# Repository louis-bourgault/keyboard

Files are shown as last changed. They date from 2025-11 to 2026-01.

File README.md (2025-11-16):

# keyboard
*my project for hack club blueprint*

## Render (made in blender, not exact but this is what I'm going for. I had some fun with lighting in this one)
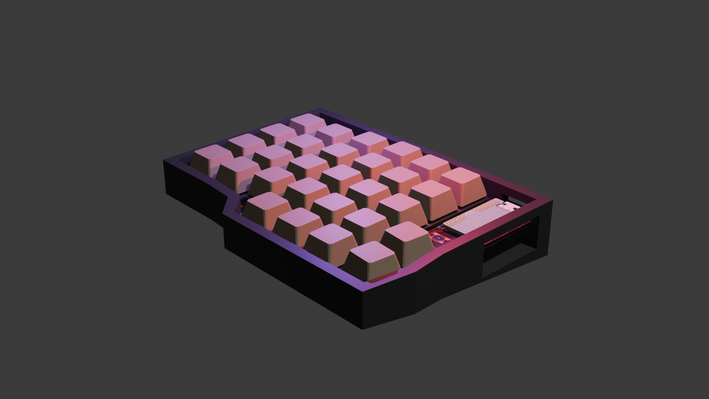
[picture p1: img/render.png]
Blender Render

### Boring edition without the lighting
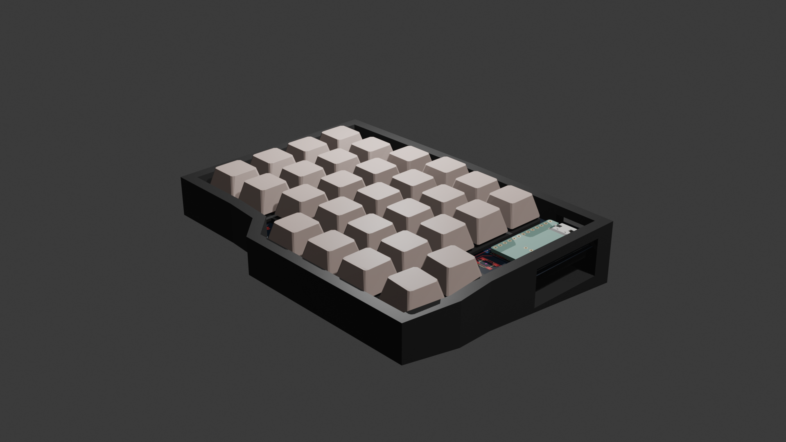
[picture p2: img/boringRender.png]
Boring Render


My design for a lily58 inspired split wireless keyboard using ergogen and kicad. It uses the NRF52840 chipset, and 3d printed parts mostly

One of my friends has significant wrist pain because his laptop keyboard is terrible. A few months ago we were planning to make a keyboard together and made things in Ergogen but never got that much further than that. Now, I have put things into kicad and done a bit more work in preparing things to be actually manufactured.
This is designed to be pretty much as cheap a keyboard as it is possible to manufacture, aiming for about AU$50 per keyboard (I am making two of these, so more like $100 total). This comes out to about $30 USD per keyboard, $60 total.

## Design
### PCB
- Ergogen for PCB design and layout drafting. It is a very simple, user friendly and powerful program. You define layouts for rows and columns, and nets to connect them
  - Note: In my Ergogen file there is a single net that was not correct, and I had to route manually in KiCad. This is the upper thumb cluster key.
- KiCad for routing the pcb. Ergogen creates the nets, so I only have to route it -- as such, there is no kicad schematic file, just a pcb file that I edited to design
- PCB: AllPcb. They had a cheap offer which let me get everything for a $2, including delivery.

### Case Design:
I use Fusion 360 in school, and am quite used to the program, so that is what I will use. As of November 1 2025, I haven't fully decided on the design -- but what I am thinking is that i will use a clean looking white coloured case, with an oiled plywood or even Jarrah laser cut bottom plate that fits in. My school has a good 3d printer (bambu p1s) and a laser cutter, so I can get everything designed there.
Ergogen outputs a DXF file for the bottom shape of the case, which is defined through the ```outlines``` section of ergogen.yml. This is the shape that I use for the outline of my PCB, so I will need to make an offset line around and use that as the case outline.
Also, since I will be taking this keyboard to and from school, I will make a hinging case to place the two halves in with foam padding for safety.

### Software
I will probably just go with zmk for this. One thing that is important to me is for the keyboard to run both wired and wireless - eg I plug one half with a usb C to A port into a school computer, and then that half talks to the other half and I can use it on computers without Bluetooth support; but I believe that QMK has this function so I will just use that. Potentially, if I have extra time, then I could code something custom in C, but I am not sure whether this is feasible at this point and with exams coming up.

Note: this software is in a seperate repo because of the way that ZMK works. The repo is [louis-bourgault/zmk-config](https://github.com/louis-bourgault/zmk-config)

# Images
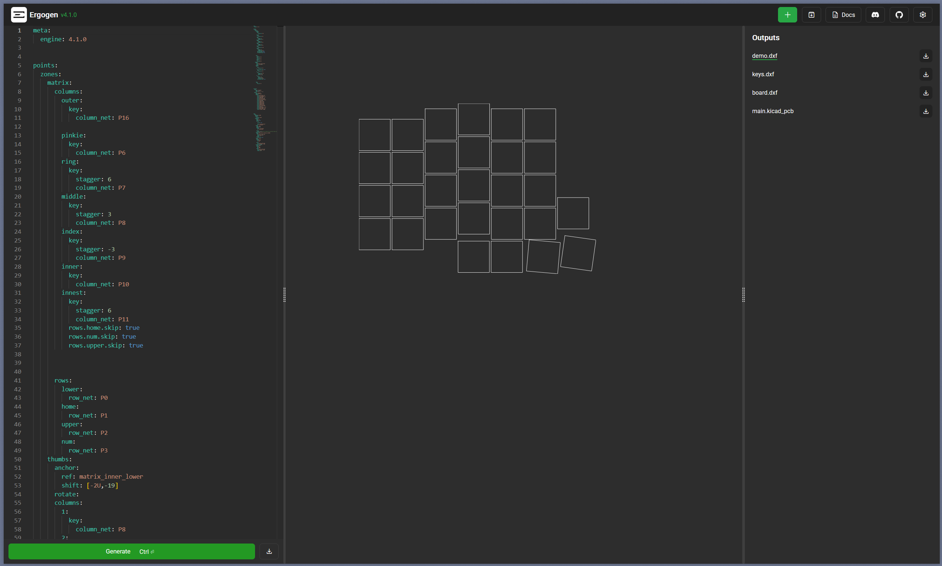
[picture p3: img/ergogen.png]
Initial Ergogen Design

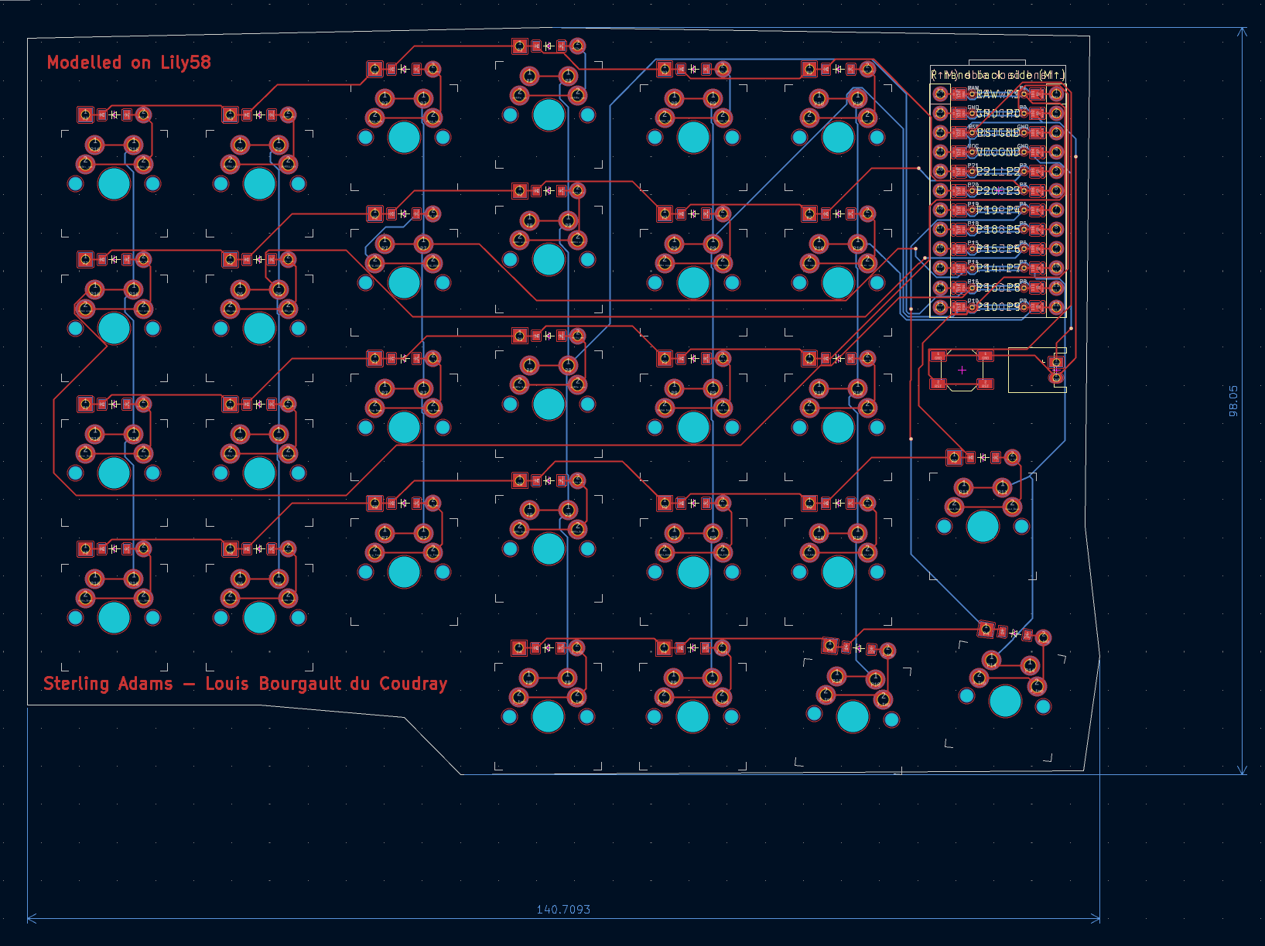
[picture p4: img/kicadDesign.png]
Kicad PCB, ready to be ordered

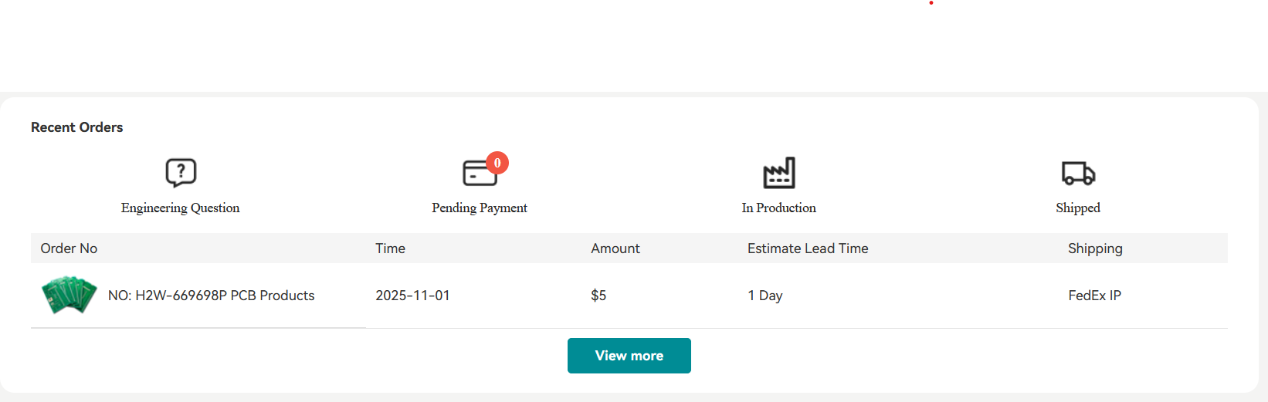
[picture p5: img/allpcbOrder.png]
Allpcb Order

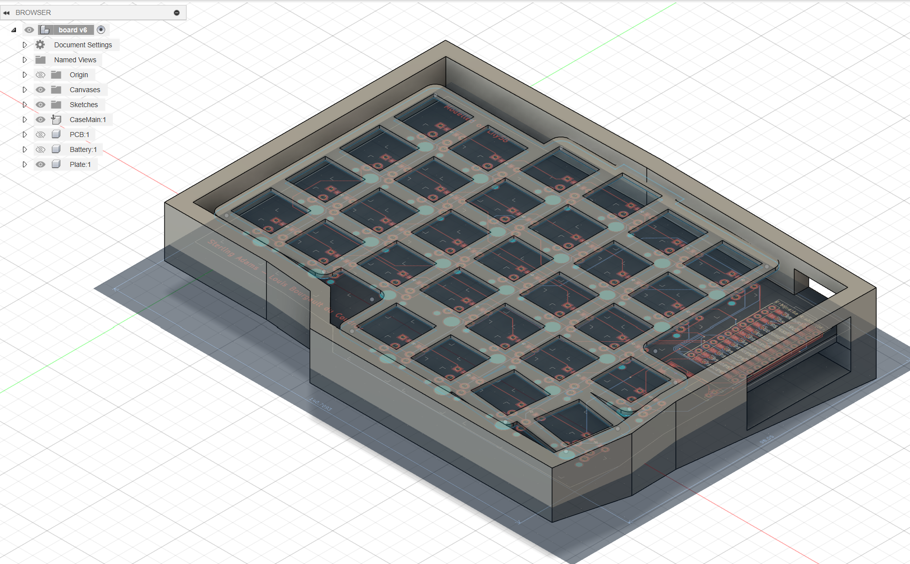
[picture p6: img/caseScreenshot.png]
Screenshot of case design in Fusion 360


# Bill of Materials

|Component Type |Item Link |Quantity needed|Relevant Specifications |Tax % (if not included)|Price each (AUD)|Total Cost (AUD)|Total Cost (USD) (using 1 AUD = 0.65 USD)|Running Cost (AUD|Running Cost (USD)|Note |
|---|---|---|---|---|---|---|---|---|---|---|
|Battery * 4 |https://www.aliexpress.com/item/1005006924508264.html?mp=1|1 |3.7v, 400mAh, 53x36x6mm, JSTPH|0.00% |$18.40 |$18.40 |$11.96 |$18.40 |$11.96 | |
|NRF52840 |https://www.aliexpress.com/item/1005006035267231.html? |4 | |10.00% |$5.65 |$24.86 |$16.16 |$43.26 |$28.12 | |
|Keyboard Switch * 110|https://www.aliexpress.com/item/1005006376024657.html?mp=1|1 |Gateron Brown * 110 |10.00% |$18.33 |$20.16 |$13.11 |$63.42 |$41.22 |This is using my Welcome Deal on Aliexpress |
|Keyboard Switch * 10 |https://www.aliexpress.com/item/1005006376024657.html?mp=1|1 |Gateron Yellow * 10 |10.00% |$4.70 |$5.17 |$3.36 |$68.59 |$44.59 |Supplemental Switches, not on welcome deal so substantially more expensive. Will use different type of switch (linear instead of tactile) for modifier keys|
|Diodes * 200 |https://www.aliexpress.com/item/1005009896621714.html |1 |Basic 1n4148 diodes |10.00% |$5.94 |$6.53 |$4.25 |$75.13 |$48.83 | |
|PCB * 5 |AllPCB |1 | |0.00% |$2.14 |$2.14 |$1.39 |$77.27 |$50.22 |already purchased |
|Keycaps * 80 |https://www.aliexpress.com/item/1005007415198959.html?mp=1|2 | |10.00% |$13.58 |$29.88 |$19.42 |$107.14 |$69.64 | |

# Note on Pricing
Since a lot of these sites have little fees that are hard to deal with on a one by one basis (such as payment processing fees, et cetera). So, the final numbers as given at checkout are slightly different.
Additionally, there is a chance that these prices may fluctuate. If they go up at all, I am able to cover the cost (I am willing to spend a bit of my money on this, and don't need a grant for all of it).

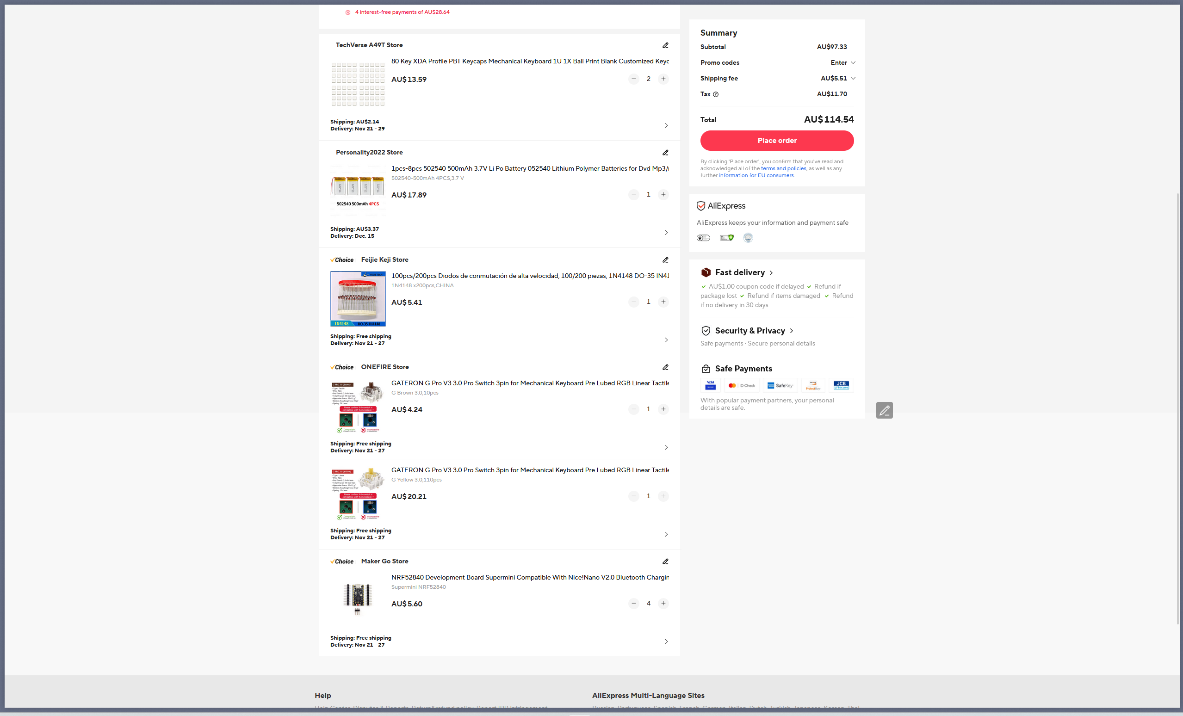
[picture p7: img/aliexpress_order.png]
Aliexpress Order

Allpcb
Note: this order actually cost me $2.14, it's just not showing the right amount because that was a one time discount

Prices:
- Aliexpress: AU$114.54
- Allpcb: AU$2.14

Total: AU$116.68
In USD: US$76.20
Note: if I do not qualify for a full support, i can cover a portion of it.

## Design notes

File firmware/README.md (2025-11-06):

# Firmware

Since this board is bluetooth, it uses the ZMK firmware setup, and it is reccomended to keep this in a different repo since ZMK compiles through Github actions.
This repository is [louis-bourgault/zmk-config](https://github.com/louis-bourgault/zmk-config)

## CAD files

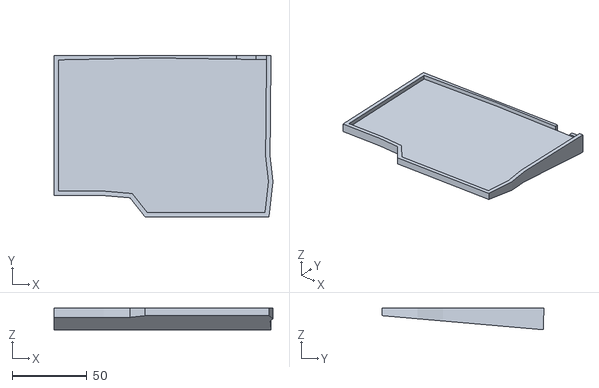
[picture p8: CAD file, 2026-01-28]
case/newcase.stl
146.7 x 108.2 x 14.4

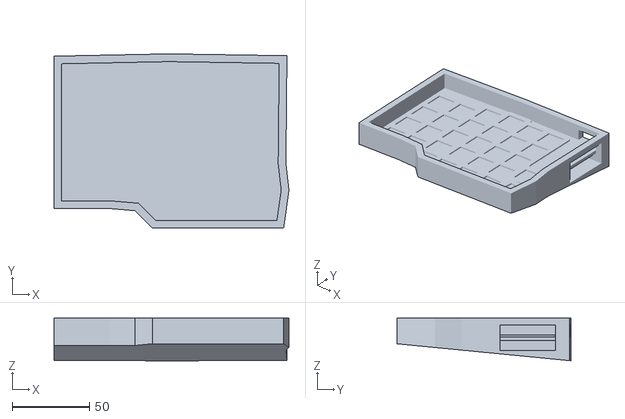
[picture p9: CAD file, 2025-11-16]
case/board v6.stl
151.8 x 112.5 x 27.5

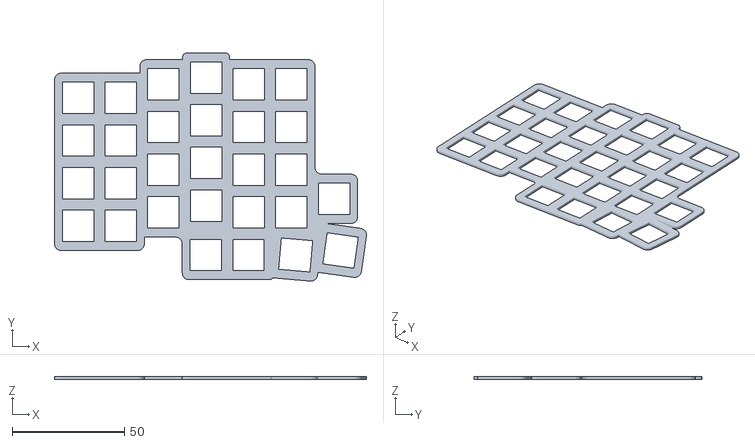
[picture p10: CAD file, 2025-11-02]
case/plate_v1.stl
139.0 x 101.7 x 1.20

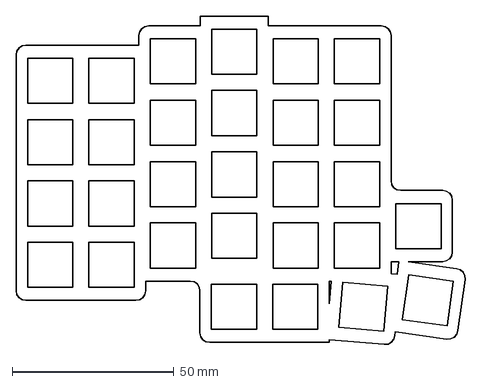
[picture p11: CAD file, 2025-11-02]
case/cutout.dxf
139.2 x 101.8 mm

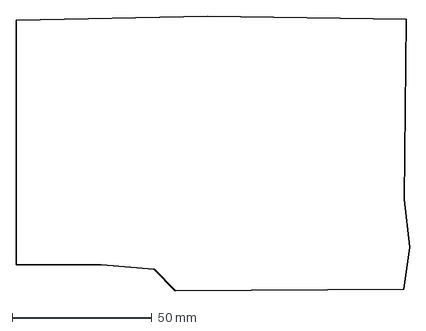
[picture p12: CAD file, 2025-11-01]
case/board.dxf
140.7 x 98.1 mm

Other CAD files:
case/case_v1.step
case/case_v1.3mf
case/case_v1.f3d
case/case_v1.stl
case/newcase v2.f3d
roughmodel.blend

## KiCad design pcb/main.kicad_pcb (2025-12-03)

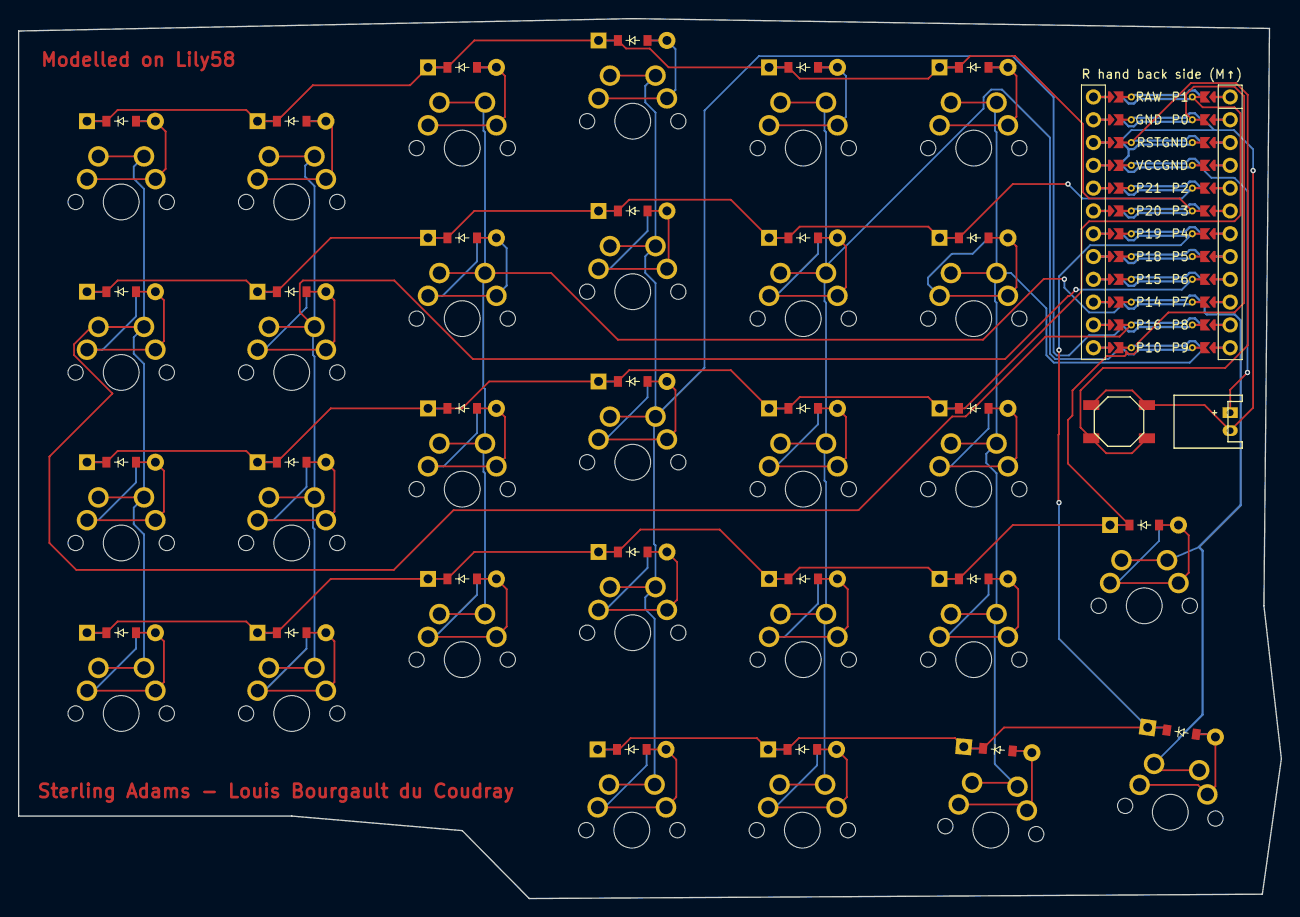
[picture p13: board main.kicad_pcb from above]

Board: 2 copper layers, 140.7 x 98.1 mm, 61 parts (0 on the bottom side), 44 nets.

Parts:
B1: SW_TACT_ALPS_SKQGABE010
D1, D2, D3, D4, D5, D6, D7, D8, D9, D10, D11, D12, D13, D14, D15, D16, D17, D18, D19, D20, D21, D22, D23, D24, D25, D26, D27, D28, D29: ComboDiode
JST1: JST_PH_S2B-PH-K_02x2.00mm_Angled
MCU1: mcu_supermini_nrf52840
S1, S2, S3, S4, S5, S6, S7, S8, S9, S10, S11, S12, S13, S14, S15, S16, S17, S18, S19, S20, S21, S22, S23, S24, S25, S26, S27, S28, S29: MX

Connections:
1_top: D26.2, S26.2
2_top: D27.2, S27.2
3_top: D28.2, S28.2
4_top: D29.2, S29.2
GND: B1.1, JST1.2, MCU1.103, MCU1.104, MCU1.123
P0: D1.1, D5.1, D9.1, D13.1, D17.1, D21.1, D25.1, MCU1.102
P1: D2.1, D6.1, D10.1, D14.1, D18.1, D22.1, MCU1.101
P2: D3.1, D7.1, D11.1, D15.1, D19.1, D23.1, MCU1.105
P3: D4.1, D8.1, D12.1, D16.1, D20.1, D24.1, MCU1.106
P4: D26.1, D27.1, D28.1, D29.1, MCU1.107
P6: MCU1.109, S5.1, S6.1, S7.1, S8.1
P7: MCU1.110, S9.1, S10.1, S11.1, S12.1
P8: MCU1.111, S13.1, S14.1, S15.1, S16.1, S26.1
P9: MCU1.112, S17.1, S18.1, S19.1, S20.1, S27.1
P10: MCU1.113, S21.1, S22.1, S23.1, S24.1, S28.1
P14: MCU1.115, S29.1
P16: MCU1.114, S1.1, S2.1, S3.1, S4.1
RST: B1.2, MCU1.122
VCC: JST1.1, MCU1.121
index_home: D18.2, S18.2
index_lower: D17.2, S17.2
index_num: D20.2, S20.2
index_upper: D19.2, S19.2
inner_home: D22.2, S22.2
inner_lower: D21.2, S21.2
inner_num: D24.2, S24.2
inner_upper: D23.2, S23.2
innest_lower: D25.2, S25.2
middle_home: D14.2, S14.2
middle_lower: D13.2, S13.2
middle_num: D16.2, S16.2
middle_upper: D15.2, S15.2
outer_home: D2.2, S2.2
outer_lower: D1.2, S1.2
outer_num: D4.2, S4.2
outer_upper: D3.2, S3.2
pinkie_home: D6.2, S6.2
pinkie_lower: D5.2, S5.2
pinkie_num: D8.2, S8.2
pinkie_upper: D7.2, S7.2
ring_home: D10.2, S10.2
ring_lower: D9.2, S9.2
ring_num: D12.2, S12.2
ring_upper: D11.2, S11.2

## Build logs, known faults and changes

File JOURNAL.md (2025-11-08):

<!--
  ===================    !!READ THIS NOTICE!!   ====================
  DO NOT edit this file manually. Your changes WILL BE OVERWRITTEN!
  This journal is auto generated and updated by Hack Club Blueprint.
  To edit this file, please edit your journal entries on Blueprint.
  ==================================================================
-->

## 11/1/2025 2:10 PM - First Journal Entry  

This is a project that i have been working on for a bit. It's for me and a friend from school, who has wrist pain and his laptop keyboard is absolutely terrible. The ergogen config was made about a month ago and i haven't worked on it for a while because i was busy but i routed it today on the pcb in kicad and prepared it to be ordered from allpcb.
The setup is reversible and designed to cost about AU$50 (about US$30) per pair of boards -- i haven't made a full BOM yet but that's next i think.
  

## 11/1/2025 2:50 PM - Fixed routing traces that showed as unconnected  

kicad was being painful and saying that i hadn't routed things that i was pretty sure i'd routed (since its dual sided and reversible it was registering that one side did not connect properly to the other. Anyway, I just made alternate tracks so that the energy could flow on two different paths just in case, and that made it be quiet. DRC doesn't show any critical warnings any more
.

## 11/1/2025 3 PM - Exported Gerbers and Ordered PCB  

I saw that allpcb was offering manufacturing and delivery for US $1 so i just impulsively exported my gerbers and ordered some pcbs! They should come in 3 days or so -- I won't have any electrical components by that time to attatch to them, but it will be cool to look at and will help me design my case around them.




## 11/1/2025 9 PM - Created first draft of BOM  

Did some research on sourcing of parts and how expensive everything is going to be, and made a first draft of a BOM in libreoffice. Honestly, less than I thought -- about 80 australian or 55 american dollars for 2 keyboards, fully wireless and split.
I did include welcome deal for the switches, which I am going to make use of, but didn't use any of the aliexpress sales which are on all the time. Hopefully that will bring it down even more



## 11/2/2025 1 PM - Started work on case design  



Working on Fusion 360 design -- looks pretty good so far! Just designed a simple case.
Halfway through I realised that I'd been designing in non parametric mode. Why does fusion even have that? There's nothing that i would need to go back and change though, so i don't think it'll be a problem.  

## 11/2/2025 4 PM - Added plate to the fusion file  

Also exported everything that i've made as stls and put my fusion document into there for the case. Ergogen is actually kind of amazing for this kind of thing -- it let me define a case outline and download it as a dxf, and then i could just chuck it into Fusion and extrude and it's now part of my main design.
All of these new files are on the github repo
getting close to submitting now!


## 11/2/2025 5 PM - Made Initial Firmware  

I set up zmk with my pin layout. Well, with quite a lot of help from Claude. 
Zmk is very complicated, and I don't want to make a full layout until I have the hardware with me ready to play with. So, I just made a basic one for now




## 11/6/2025 - Finalised Bill of Materials  

I found some rather cheap keycaps that I can use! They cost about 20 cents australian each, and I'll get free shipping on my first order so i think that will be OK.
I'm actually pretty proud of how cheaply I'm going to be able to do this. US$70 is pretty good for two keyboards, it seems. A lot of this is, of course, because of welcome deals. 

Also, I said I wouldn't in the last entry, but did some brainstorming on keyboard layouts on paper. I printed off a sheet to fill in and played around with it -- i also gave one to the friend I'm doing it with. I won't put it into the firmware until I've got actual hardware ready to work with, but it's a start

WIN_20251103_08_53_14_ProblankKeyMaps

## 11/8/2025 - Redid BOM  

A few things have sold out since I made my bom, which was a bit annoying, but i redid those things. Also, dealing with pricing is painful especially on sites that don't give itemised reports for tax (speaking of which, Australia seems to have rather complicated and hard to account for import taxes on things). Because of this, the BOM does not entirely match the amount in the screenshots, because I couldn't figure out how to itemise these fees with the framework that I had set up.
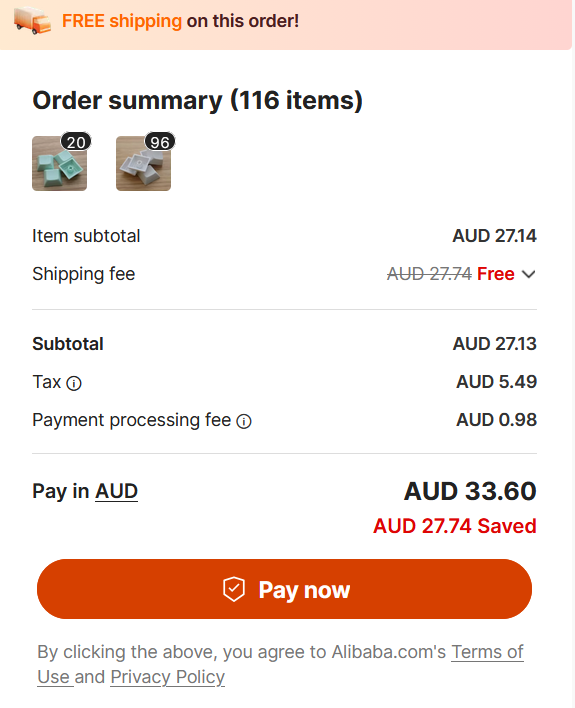
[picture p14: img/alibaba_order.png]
alibaba_order
Anyway, here are the cart screenshotsaliexpress_order
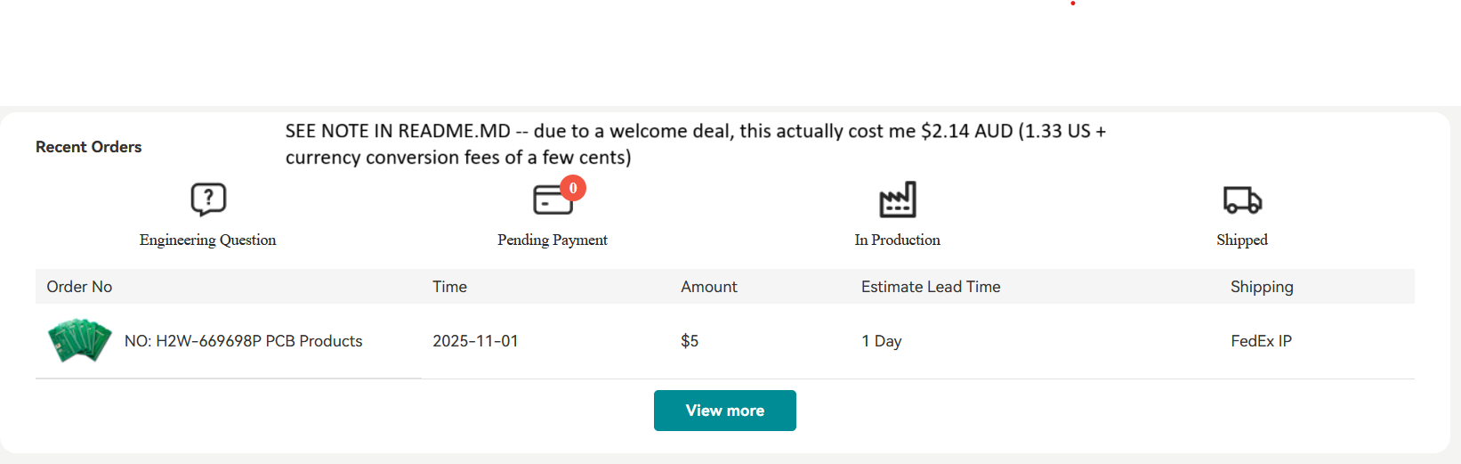
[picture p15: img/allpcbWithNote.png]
allpcbWithNote
ebay_order

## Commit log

2025-11-01 exported gerbers ready to put on allpcb
    [main-B_Cu.gbr, main-B_Mask.gbr, main-B_Paste.gbr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]
2025-11-01 updated readme and added gerbers.
2025-11-01 Initial bill of materials draft
    [board.dxf, bom.ods]
2025-11-02 added fusion 360 document and stl files for prints
    [bom.ods, case_v1.f3d, case_v1.stl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]
2025-11-05 added screenshot of case design
    [bom.ods]
2025-11-06 Updated Bill of Materials to final version
    [bom.csv]
2025-11-06 added gcode from Bambu Studio for printing
    [case_v1.3mf]
2025-11-06 removed more tracking links
    [bom.csv, bom.ods]
2025-11-08 Updated pricing with new things that had sold out, and cart screenshots
    [bom.csv, bom.ods]
2025-11-08 exported newest versions of step and f3d files ready for submitting
    [case_v1.f3d, case_v1.step]
2025-11-15 Updated BOM
    [bom.csv, bom.ods]
2025-11-16 Added new render
    [board v6.stl, roughmodel.blend]
2026-01-18 pcb annotations
    [main.kicad_pcb]
2026-01-28 Added new case that takes into account cutouts for the plate
    [newcase v2.f3d, newcase.stl]
